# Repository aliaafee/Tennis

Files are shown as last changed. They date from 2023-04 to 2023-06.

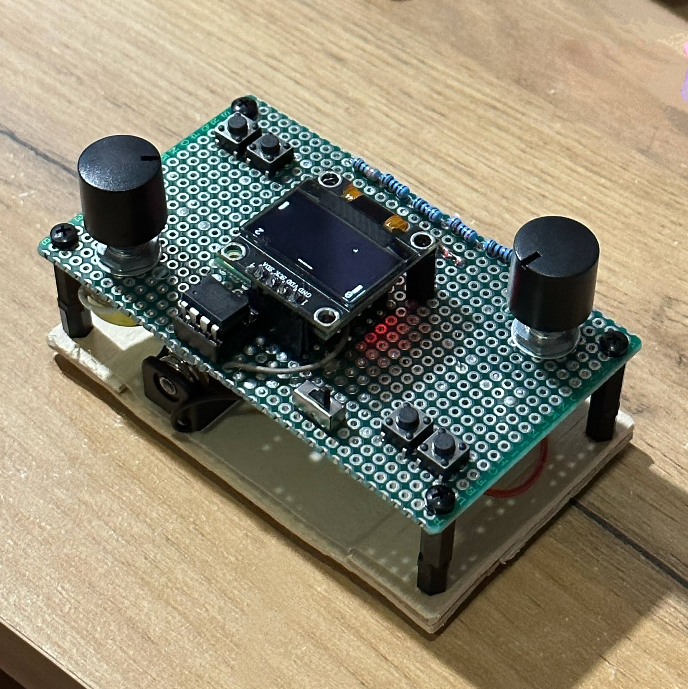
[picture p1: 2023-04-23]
photos/IMG_4150 Copy.JPG

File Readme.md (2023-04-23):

# Tennis

Pong like two player game that runs on ATtiny85 Microcontroller, with SSD1306 OLED (128x64 0.96 inch) display. Input with potentiometers, one for each player, and four buttons.

## Preamble

### Setup ArduinoISP

* Build and Upload ArduinoISP Program to an Ardunio UNO / Nano or other appropriate board.
* Add Additional Board Manager URL for ATtiny85 (File > Preferences): https://raw.githubusercontent.com/damellis/attiny/ide-1.6.x-boards-manager/package_damellis_attiny_index.json
* Install Attiny Package from Boards Manager

### Prepare ATtiny85 for Programming

* Hookup Attiny to Arduino ISP (Pin1 -> D10, Pin4 -> GND, Pin5 -> D11, Pin6 -> D12, Pin7 -> D13, Pin8 -> GND)
* Select Board : ATtiny25/45/85
* Select Processor: Attiny85
* Select Clock: Internal 8MHz
* Select port where ArduinoISP is pulgged int.
* Select programmer: Arduino ISP
* Burn Bootloader

## Build and Upload the Project

* Install PlatformIO
* Install required depenencies `pio lib install`
* Update `board` and `upload_port` to appropriate values in `platformio.ini`
* Build `pio run`
* Upload to device `pio run -t upload`

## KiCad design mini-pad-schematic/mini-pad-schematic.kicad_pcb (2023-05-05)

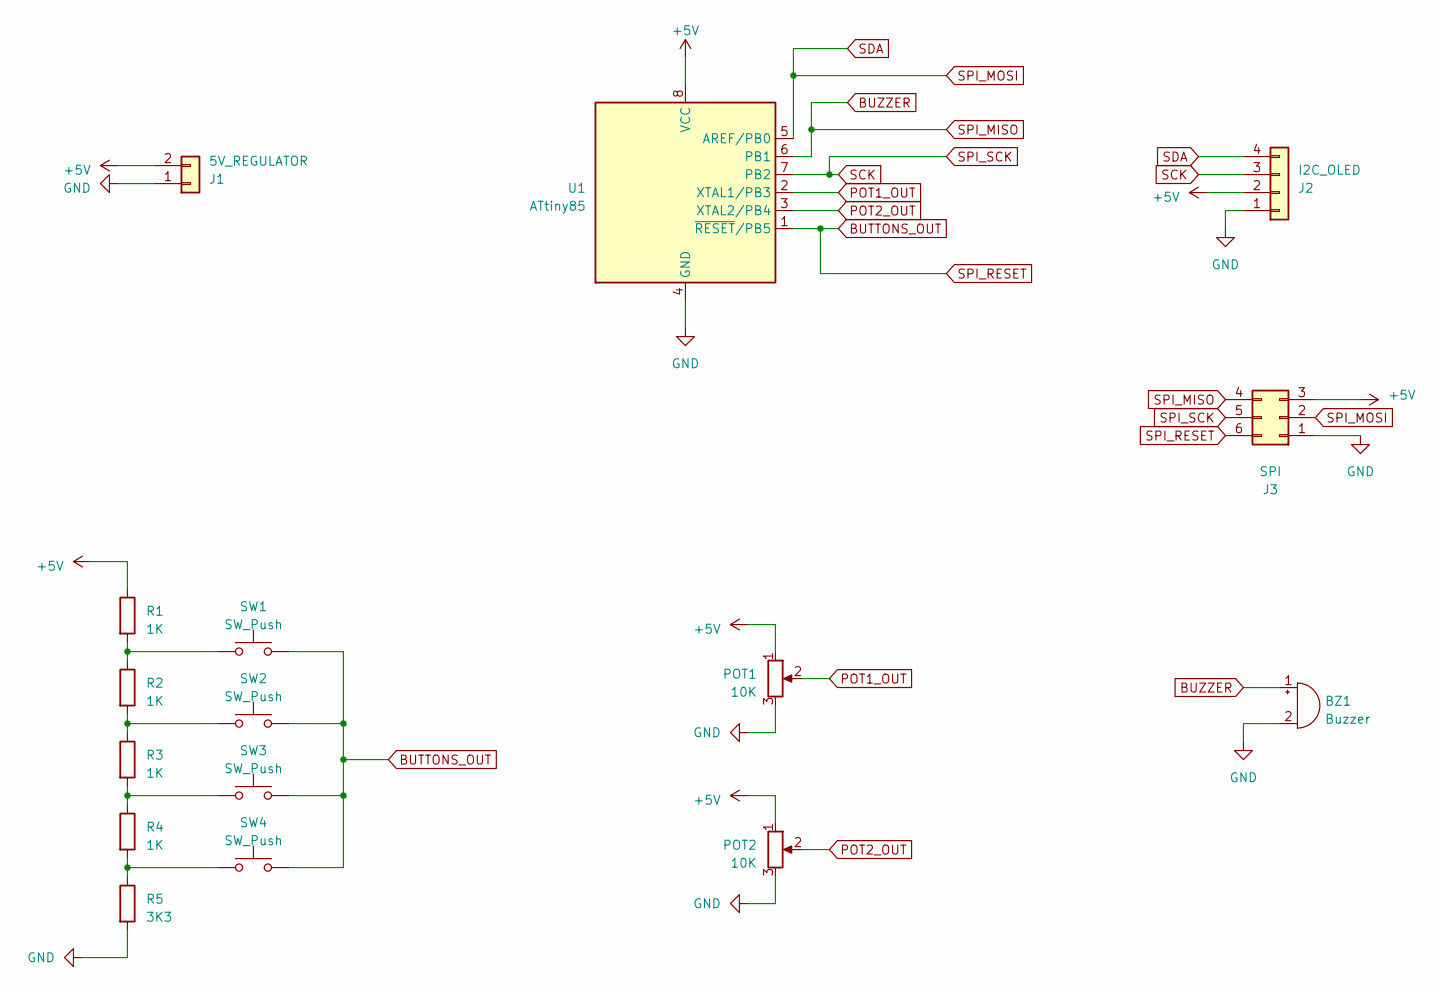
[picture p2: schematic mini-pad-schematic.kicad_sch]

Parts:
BZ1: Buzzer; Buzzer_12x9.5RM7.6
J1: 5V_REGULATOR; PinHeader_1x02_P2.54mm_Vertical
J2: I2C_OLED; PinSocket_1x04_P2.54mm_Vertical
J3: SPI; PinSocket_2x03_P2.54mm_Vertical
POT1, POT2: 10K; Potentiometer_Alpha_RD901F-40-00D_Single_Vertical
R1, R2, R3, R4: 1K; R_Axial_DIN0207_L6.3mm_D2.5mm_P7.62mm_Horizontal
R5: 3K3; R_Axial_DIN0207_L6.3mm_D2.5mm_P7.62mm_Horizontal
SW1, SW2, SW3, SW4: SW_Push; SW_PUSH_6mm_H5mm
U1: ATtiny85; DIP-8_W7.62mm

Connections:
+5V: J1.2, J2.2, J3.3, POT1.1, POT2.1, R1.1, U1.8 (VCC)
BUTTONS_OUT: J3.6, SW1.2, SW2.2, SW3.2, SW4.2, U1.1 (~RESET/PB5)
BUZZER: BZ1.1 (-), J3.4, U1.6 (PB1)
GND: BZ1.2 (+), J1.1, J2.1, J3.1, POT1.3, POT2.3, R5.2, U1.4 (GND)
unnamed: R1.2, R2.1, SW1.1
unnamed: R2.2, R3.1, SW2.1
unnamed: R3.2, R4.1, SW3.1
unnamed: R4.2, R5.1, SW4.1
POT1_OUT: POT1.2, U1.2 (XTAL1/PB3)
POT2_OUT: POT2.2, U1.3 (XTAL2/PB4)
SCK: J2.3, J3.5, U1.7 (PB2)
SDA: J2.4, J3.2, U1.5 (AREF/PB0)

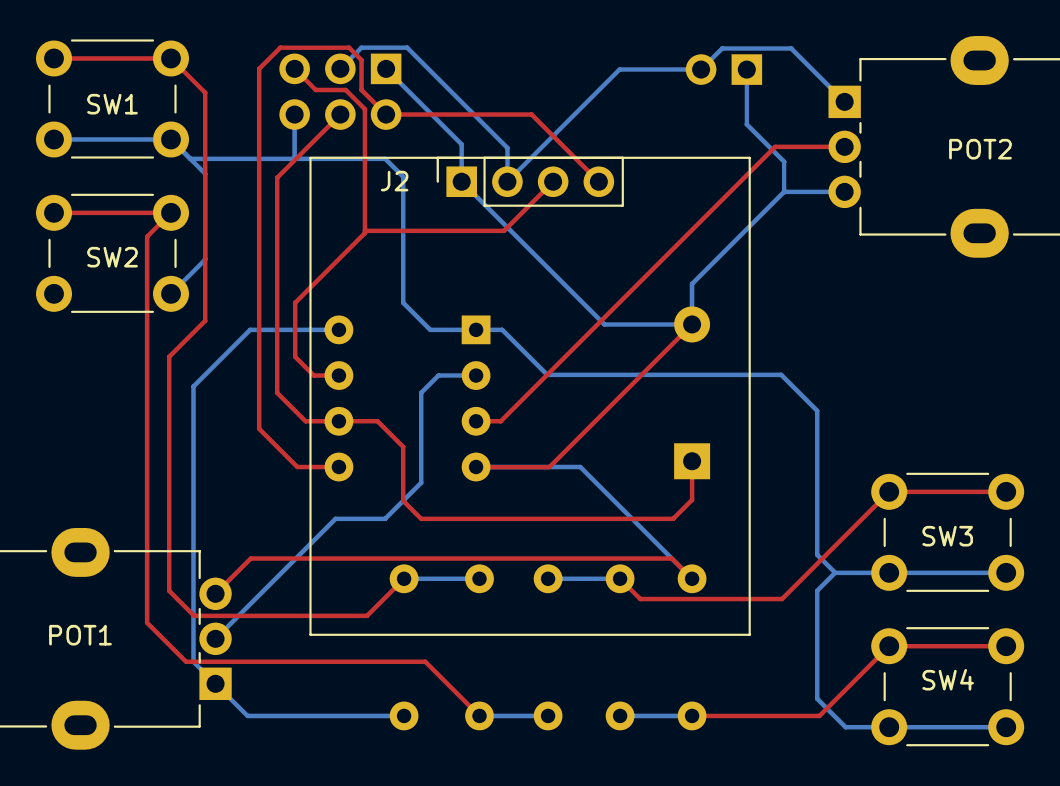
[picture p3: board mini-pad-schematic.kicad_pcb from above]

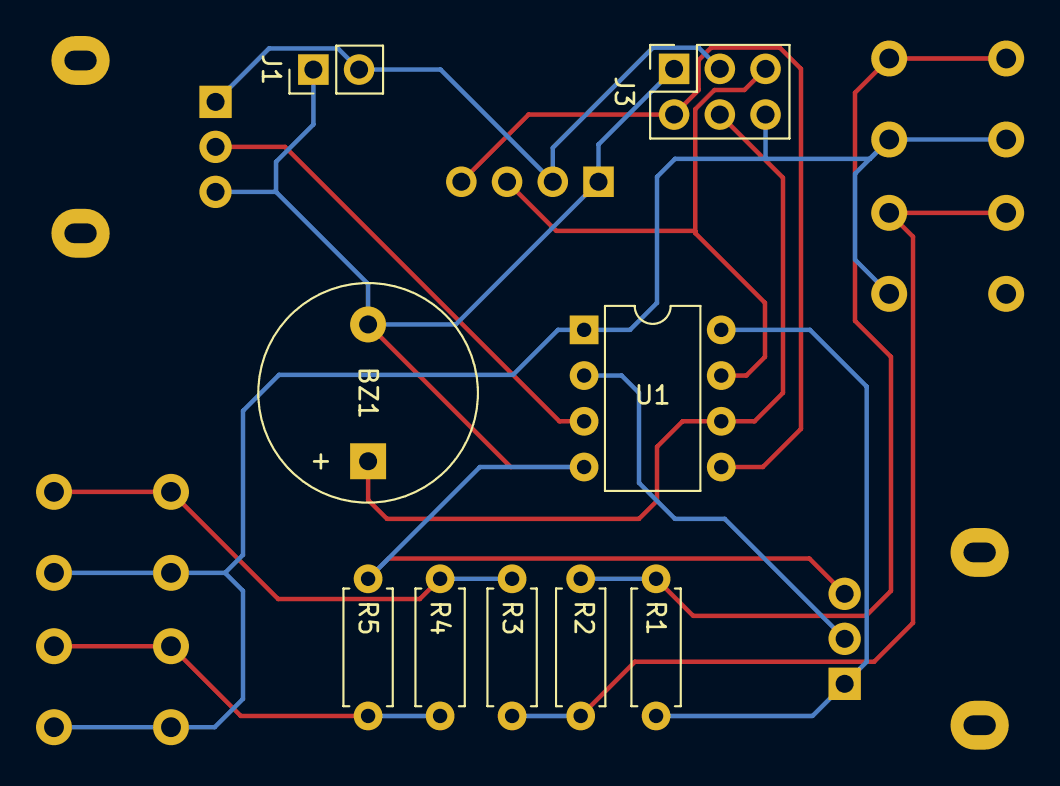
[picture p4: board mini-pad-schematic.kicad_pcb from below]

Board: 2 copper layers, 16 parts (9 on the bottom side), 12 nets.

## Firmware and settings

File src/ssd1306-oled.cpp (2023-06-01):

/*!
 * @file ssd1306-oled.cpp
 *
 * SSD1306 library for monochrome OLED displays
 * This is a stripped down version based on AlexGyver's 
 * GyverOLED https://github.com/GyverLibs/GyverOLED.
 * 
 * This library is optimized to work with Attiny85
 * and has limited functionality but uses much less
 * memory. Desiged to only work with 128x64 display
 * using the I2C interface.
 *
 */

#include "ssd1306-oled.h"

void SSD1306_OLED::begin()
{
  init();
}

void SSD1306_OLED::init()
{
  Wire.begin();
  sendCommand(OLED_DISPLAY_OFF);
  sendCommand(OLED_CLOCKDIV);
  sendCommand(0x80);
  sendCommand(OLED_CHARGEPUMP);
  sendCommand(0x14);
  sendCommand(OLED_ADDRESSING_MODE);
  sendCommand(OLED_VERTICAL);
  sendCommand(OLED_NORMAL_H);
  sendCommand(OLED_NORMAL_V);
  sendCommand(OLED_CONTRAST);
  sendCommand(0x7F); // value
  sendCommand(OLED_SETVCOMDETECT);
  sendCommand(0x40); // value
  sendCommand(OLED_NORMALDISPLAY);
  sendCommand(OLED_DISPLAY_ON);
}

void SSD1306_OLED::sendCommand(uint8_t command)
{
  Wire.beginTransmission(_address);
  Wire.write(OLED_COMMAND_MODE);
  Wire.write(command);
  Wire.endTransmission();
}

void SSD1306_OLED::beginCommand()
{
  Wire.beginTransmission(_address);
  Wire.write(OLED_COMMAND_MODE);
}

void SSD1306_OLED::endCommand()
{
  Wire.endTransmission();
}

void SSD1306_OLED::beginData()
{
  Wire.beginTransmission(_address);
  Wire.write(OLED_DATA_MODE);
}

void SSD1306_OLED::endData()
{
  Wire.endTransmission();
}

void SSD1306_OLED::write(uint8_t data)
{
  Wire.write(data);
}

void SSD1306_OLED::setWindow(int x0, int y0, int x1, int y1)
{
  beginCommand();
  write(OLED_COLUMNADDR);
  write(constrain(x0, 0, _maxX));
  write(constrain(x1, 0, _maxX));
  write(OLED_PAGEADDR);
  write(constrain(y0, 0, _maxRow));
  write(constrain(y1, 0, _maxRow));
  endCommand();
}

void SSD1306_OLED::fillscreen(uint8_t fill)
{
  for (int x = 0; x <= _maxX; x += 12)
  {
    for (int y = 0; y <= _maxRow; y += 1)
    {
      setWindow(x, y, x + 12, y);
      beginData();
      for (int i = 0; i < 12; i++)
      {
        write(fill);
      }
      endData();
    }
  }
}

void SSD1306_OLED::clear()
{
  fillscreen(0);
}

void SSD1306_OLED::fillRect(int x0, int y0, int w, int h, byte fill)
{
  if (fill)
    fill = 255;
  setWindow(x0, y0 >> 3, x0 + w, (y0 + h) >> 3);
  beginData();
  for (int i = 0; i < w * h; i++)
  {
    write(fill);
  }
  endData();
}

void SSD1306_OLED::dot(int x, int y, byte fill)
{
  setWindow(x, y >> 3, 1, 1);
  beginData();
  write(fill << (y & 0b111));
  endData();
}

void SSD1306_OLED::fastLineH(int y, int x0, int x1, byte fill)
{
  byte data = fill << (y & 0b111);
  y >>= 3;
  setWindow(x0, y, x1, y);
  beginData();
  for (int x = x0; x < x1; x++)
    write(data);
  endData();
}

void SSD1306_OLED::fastLineV(int x, int y0, int y1, byte fill)
{
  if (fill)
    fill = 255;
  byte shift = y0 & 0b111;
  byte shift2 = 8 - (y1 & 0b111);
  if (shift2 == 8)
    shift2 = 0;
  int height = y1 - y0;
  y0 >>= 3;
  y1 = (y1 - 1) >> 3;
  byte numBytes = y1 - y0;
  setWindow(x, y0, x, y1);
  beginData();
  if (numBytes == 0)
  {
    if (_inRange(y0, 0, _maxRow))
      write((fill >> (8 - height)) << shift);
  }
  else
  {
    if (_inRange(y0, 0, _maxRow))
      write(fill << shift);
    y0++;
    for (byte i = 0; i < numBytes - 1; i++, y0++)
      if (_inRange(y0, 0, _maxRow))
        write(fill);
    if (_inRange(y0, 0, _maxRow))
      write(fill >> shift2);
  }
  endData();
}

void SSD1306_OLED::setCursorXY(int x, int y)
{
  setWindow(x, y >> 3, x + _maxX, (y >> 3));
}

void SSD1306_OLED::setCursor(int col, int row)
{
  setWindow((col * 6), row, (col * 6) + _maxX, row);
}

uint8_t SSD1306_OLED::getFont(uint8_t font, uint8_t row)
{
  if (row > 4)
    return 0;
  font = font - '0' + 16;
  if (font <= 95)
  {
    return pgm_read_byte(&(_charMap[font][row]));
  }
  else if (font >= 96 && font <= 111)
  {
    return pgm_read_byte(&(_charMap[font + 47][row]));
  }
  else if (font <= 159)
  {
    return pgm_read_byte(&(_charMap[font - 17][row]));
  }
  else
  {
    return pgm_read_byte(&(_charMap[font - 1][row]));
  }
}

void SSD1306_OLED::writeChar(uint8_t data)
{
  beginData();

  for (uint8_t col = 0; col < 6; col++)
  {
    uint8_t bits = getFont(data, col);
    write(bits);
  }
  endData();
}

void SSD1306_OLED::clearChar()
{
  beginData();

  for (uint8_t col = 0; col < 6; col++)
  {
    write(0);
  }
  endData();
}

void SSD1306_OLED::print(String &line)
{
  for (unsigned int i = 0; i < line.length(); i++)
  {
    writeChar(line.charAt(i));
  }
}

void SSD1306_OLED::print(int number)
{
  _printDigits(number);
}

void SSD1306_OLED::clearPrint(int length)
{
  for (int i = 0; i < length; i++)
  {
    clearChar();
  }
}

void SSD1306_OLED::fillCell(int col, int row)
{
  setCursor(col, row);

  beginData();
  write(0x00);
  for (uint8_t col = 0; col < 5; col++)
  {
    write(0xfc);
  }
  endData();
}

void SSD1306_OLED::clearCell(int col, int row)
{
  setCursor(col, row);

  beginData();
  for (uint8_t col = 0; col < 6; col++)
  {
    write(0x00);
  }
  endData();
}

bool SSD1306_OLED::_inRange(int x, int mi, int ma)
{
  return x >= mi && x <= ma;
}

void SSD1306_OLED::_printDigits(int number)
{
  if (number >= 10)
    _printDigits(number / 10);

  int digit = number % 10;
  char c = '0' + digit;

  writeChar(c);
}

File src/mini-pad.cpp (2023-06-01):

#include "mini-pad.h"

void MiniPad::begin(App *app)
{
    pinMode(POT_RIGHT, INPUT);
    pinMode(POT_LEFT, INPUT);

    pinMode(BTN_INPUT, INPUT_PULLUP);

    pinMode(BUZZER, OUTPUT);

    screen->init();
    screen->clear();

    currentApp = app;
}

void MiniPad::loop()
{
    if (currentApp == NULL)
        return;

    pressedButton_ = getButtonValue_();

    (currentApp)->loop();

    // screen->setCursor(0, 6);
    // screen->print("b=");
    // screen->print(buttonReading_);
}

int MiniPad::getPotValue_(uint8_t potPin)
{
    return analogRead(potPin);
}

void MiniPad::playTone(unsigned long frequency, unsigned long duration)
{
    tone(BUZZER, frequency, duration);
}

int MiniPad::getButtonValue_()
{
    /*
    Button setup as potential divider and the reset pin used as input

        5v -
            |
            1K
            |---/ S1---
            1K         |
            |---/ S2---|
            1k         |-----RST Pin (A0)
            |---/ S3---|
            1K         |
            |---/ S4---
            3K3
            |
        GND-

        0 no button pressed
    */

    buttonReading_ = analogRead(BTN_INPUT);

    if (buttonReading_ < 550)
        return 4;
    if (buttonReading_ < 650)
        return 3;
    if (buttonReading_ < 790)
        return 2;
    if (buttonReading_ < 920)
        return 1;

    return 0;

    // return analogRead(BTN_INPUT);
}

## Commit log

2023-04-23 Added Schematic
    [mini-pad-schematic.kicad_pcb, mini-pad-schematic.kicad_sch]
2023-04-25 Added buzzer
    [mini-pad-schematic.kicad_sch]
2023-05-05 update the pcb design
    [mini-pad-schematic.kicad_pcb, mini-pad-schematic.kicad_sch]
2023-06-01 Switched to custom stripped down oled library which allows a 24% savings in Flash memory usage
